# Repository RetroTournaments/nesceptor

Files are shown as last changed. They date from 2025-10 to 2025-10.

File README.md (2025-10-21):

# NESceptor

The NESceptor is a small hardware mod that adds a USB output to a 1985 Nintendo Entertainment System.
This mod is designed to provide support for speedrunning and speedrunning competitions.
The primary use case is to:

 - Allow for live RAM watch
 - Transmit console power status
 - Transmit precise timing information

## Design Decisions

### Why this overall design?

The console is to be treated with respect.
Although nearly [62 million units](https://en.wikipedia.org/wiki/Nintendo_Entertainment_System) were sold, they are no longer manufactured and should not be unnecessarily damaged.
The case (shell) of the Nintendo Entertainment system is _not_ to be cut or irreversibly modified.
The electronics are _not_ to be irreversibly modified.

To satisfy this requirement - while also balancing the desires to be able to quickly install a NESceptor - a two-part design was chosen.
The first board sits inside the console and attaches directly to the back of the CPU via a series of castellations.
This first board provides level translation and hosts the microcontroller which does all necessary i/o and processing.

The second part sits in the small outside slot on the back of the console and is attached via double sided tape and a small cable which goes back to the in console pcb.
This second board has ESD protection and the USB port for power in and data trasmission out.

A rough block diagram is below:

```
                     +--inconsole/--------------------+   +--usbport/---------+
     +------------+  |  +--------+    +------------+  |   |                   |
     |            |  |  |        |    |            |  |   | USB connection    |
     | NES CPU    |  |  | 5V to  |    | Rp2350     |  |   |                   |
     |            |  |  | 3.3V   |    | Micro-     |  |   | ESD protection    |
     | 8 data     |  |  |        |    | controller |  |   |                   |
     | 14 addr    | --> | Level  | -> |            | ---> |                   |
     | 3 aux      |  |  | Trans- |    | Watching / | <--- |                   |
     | --         |  |  | lators |    | Filtering  |  |   |                   |
     | 25 signals |  |  |        |    |            |  |   |                   |
     |            |  |  |        |    |            |  |   |                   |
     +------------+  |  +--------+    +------------+  |   |                   |
                     +--------------------------------+   +-------------------+ 
```

### Why Castellations?

The `inconsole` pcb is connected to the NES CPU with 40 castellations.
Consider:

- Removing the CPU and/or PPU can be difficult for novices (ahem) and requires patience, dedicated tools, and practice.
  Then once removed a socket is installed, and the CPU/PPU have to be installed into yet another socket, and the whole thing is fiddly and may lead to damage.
- The CPU itself is not subjected to heat or potential damage (when removing it), and is left basically alone with this design.
- A flex pcb was tried at one point, but it proved very difficult to install and remove.
  Flex pcbs are also more expensive to manufacture.

The main drawback to the castellations is that they may make the nesceptor difficult to remove, although this has not been tested yet.

### Which signals are needed from the console?

The following signals are absolutely required:

- Data lines 0 to 7 (8 total), these are self explanatory!
- Address lines 0 to 10 and 13-15 (14 total). Address lines 11 and 12 are not necessary because they are [unmapped](https://www.nesdev.org/wiki/CPU_memory_map).
- `NES_RST` when low the console is off, and that is important to know.
- `M2` is the clock
- `R/W` for read / write (low is write) 

This gives a total of 25 signals.

Historically `NMI` was also watched - but it was not used in the first version.
Maybe the controller pins are important, or `IRQ`, but they were never hooked up in the original.

### Notes on level translation

The NES is a 5V system, which is relatively high by modern standards, as most modern microcontrollers only have 3.3V tolerant inputs.
For example the [RP2350 datasheet](https://datasheets.raspberrypi.com/rp2350/rp2350-datasheet.pdf) indicates a maximum 3.63V supply voltage (`IOVDD`) and `IOVDD + 0.3` as maximum input voltage.
The NES signals must be translated to not damage the microcontrollers.

The level translators must not be used to change or interact with the console whatsoever.
They are preferably unidirectional.
This is imperative to maintain the legitimacy of the speedrunning and should be easily verified by third parties.

### Why the RP2350?

An earlier version of the NESceptor used an FPGA - specifically the Lattice iCE40 HX on the Alchitry CU development board, however:

- FPGAs are expensive.
- FPGAs are difficult to program (requiring some HDL).

The RP2350 is cheaper and should be capable of reading the NESs roughly 2 MHz signals:

- [This logic analyzer project](https://github.com/gusmanb/logicanalyzer/tree/master) uses a raspberry pi pico and boasts 100Msps
- And [this one](https://github.com/dotcypress/ula) also gets similar speeds.

### Why USB

USB is simple and well supported, people probably already have a ton of cables.
This will allow for communication and power delivery.
Ethernet is not necessary in this application because the nesbox mini pc will handle that, and would introduce some additional complications when it comes to networking.
Wifi for communication is expected to be unreliable - although this is unknown.

## Dev Instructions

### PCB Development

Install [KiCad](https://www.kicad.org/) for schematics / pcb design / etc.
I just use `snap install kicad`.
This got me `kicad 9.0.1` last time.
I'm using KiCad because it's free, and this is an open source project.

### Enclosure Development

Install [OpenSCAD](https://openscad.org/) for the 3d printed usbport enclosure.
I just use `snap install openscad`.
This got me `openscad 2021.01` last time.
I'm using OpenSCAD because its free, programmatic, and this is an open source project.

### Firmware Development

Firmware is developed using the [RP2350 C/C++ SDK](https://www.raspberrypi.com/documentation/microcontrollers/c_sdk.html).

To get started you need to have cloned this repo with submodules, or else use `git submodule update --init --recursive`.
Install the necessary prerequisites for the pico sdk:

```
sudo apt install cmake gcc-arm-none-eabi libnewlib-arm-none-eabi libstdc++-arm-none-eabi-newlib
```

Then you have to initialize the cmake build system with:

```
mkdir build
cd build
../scripts/cmake.sh
```

Then to build the firmware (source code in `include/` and `src/`), simply use `make`.

To flash the firmware to the nesceptor you need to hold the bootsel button when plugging it in, and then drag and rop the completed `.uf2` file onto the device.
It should then reboot and start running immediately.

### Ordering instructions

Under construction.

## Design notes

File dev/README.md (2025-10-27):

# Dev log

## 2025-10 `testbench/` Design

Round two developing nesceptor begins.
New thoughts:

  - Document more of the development process / decisions.
  - Order everything with PCB assembly.
    I am sick of debugging soldering issues.
    I also want to be able to order more easily - and not have to spend assembly time on my side.

Today I verified that my little TXU0104PWR breakout board worked.
Also, my original connector Molex 5051104091 is on the JLCPCB Parts library!

First item to design / order is a 5051104091 -> Digital discovery adapter that allows for exploration of the signals, and allows hooking up the pico 2 for initial development.
A sort of test bench hence the directory: `testbench/`.

- 5051104091, connector to get all 40 signals from the CPU
- To 5v -> 3.3v level translater prototype
    - TLV1117LV33DCYR for 5v to 3.3v (first test for this part)
    - TXU0104 translators (second implementation of this part)
- To pins with labels (all pins!?)

Review of the connector from my current breakout installed in several NESes

```
5051104091
                    |    |
                    |    |
              40            --  +5V
              39            ->  OUT0
              38            ->  OUT1
------------  37            ->  OUT2 
              36            ->  /OE1  
              35            ->  /OE2  
              34            ->  R/W   
              33            <-  /NMI  
              32            <-  /IRQ
              31            ->  M2
              30            <-  TST (usually GND)
              29            <-  CLK
              28            <>  D0
              27            <>  D1
              26            <>  D2 
              25            <>  D3 
              24            <>  D4 
              23            <>  D5 
              22            <>  D6
              21            <>  D7
 cable        20            --  GND
              19            ->  A15
              18            ->  A14 
              17            ->  A13  
              16            ->  A12   
              15            ->  A11    
              14            ->  A10     
              13            ->  A9      
              12            ->  A8       
              11            ->  A7        
              10            ->  A6         
               9            ->  A5          
               8            ->  A4           
               7            ->  A3            
               6            ->  A2             
               5            ->  A1              
------------   4            ->  A0               
               3            <-  RST
               2            ->  AD2
               1            ->  AD1
                    |    |
                    |    |
```

The rev 1 testbench has a little section for converting the NES 5v to 3.3v, and then some translators to get the signals into the digital discovery.
I ordered it, now to wait for it to show up.

The plan for when it does is to hook it up to the nes and the [Digital Discovery](https://digilent.com/shop/digital-discovery-portable-usb-logic-analyzer-and-digital-pattern-generator/).
This will allow me to document some of the timing information I will need when developing the inconsole firmware.
I have some earlier things kicking around - but they are not in keeping with the new repo structure and philosophy with documenting everything better.

## 2025-10 `inconsole/` -- rev 0

The next pcb I have designed and ordered is a 0th revision for the inconsole.
This is to see if I can fit all the parts, if I can design and order a working RP2350 board, and many other things.

Basically just following the RP2350 hardware design document, and shooting by the hip.
Going to try the RP2354A so I don't have to worry about fitting the flash on there.
I made an initial board which has all the level translation / power stuff contained within the necessary footprint of the NES CPU, and then some extra stuff on the outside for debugging and testing.
I ordered five of these with assembly and will try to learn as many lessons as possible from this.

First few things before it has even shown up.

- Sticking to 0402 components is helpful for assembly and keeping assembly costs down.
  I did 0201 for a bit, but then it was going to require more advanced assembly and higher costs.
- Ensure hole sizes are in tolerance.
- Include the pin 0 on silkscreen to avoid back and forth email.

Waiting for it to show up, and then will test!

## 2025-10 `usbport/` -- rev 0

Before even the other two revision 0s have shown up I'm investigating the `usbport/`.
Essentially I'm just going to steal the design from the [Unified Daughterboard](https://github.com/Unified-Daughterboard/UDB-S) project - which is another open source project primarily for mechanical keyboards.
Unfortunately their original design does not fit exactly where I want this to fit, so I will have to move things around a little bit probably screwing things up in the process.

One other main consideration about the usbport is that it needs a little enclosure to keep everything neat and tidy and protected.
I was originally thinking of coming out the left of the console - but we have power out the back, and composite out the right, so would be better to not add another cable out another side.
Then I ordered a unified daughterboard just to test, and the Pico EZMate connector is so small that it fits out the expansion port directly, and does not need to come out the vents.
Going to try for out the back on the 0th revision.

The back slot is about 99mm long, 12.5mm deep, ~16 mm wide (15.9 at 'top', 16.5 at 'bottom').
Let's imagine then 1.5mm thick walls on both sides, gives me a 12 mm wide pcb, 1.6mm thick.
I do not think I need to go the full length, but it would make it a bit easier for pushing the usb cable in to have some backing.
Regardless the PCB itself does not need to go to the back.

In keeping with stealing from the unified daughterboard project, we'll be using this [usb c connector - C165948](https://jlcpcb.com/partdetail/Korean_HropartsElec-TYPE_C_31_M12/C165948).

For the enclosure thinking of starting with a single hole in the middle M3 with [threaded inserts](https://www.mcmaster.com/products/threaded-inserts/threaded-inserts-3~/tapered-heat-set-inserts-for-plastic-7/).

## 2025-10 `inconsole/` -- rev 0 continued

The inconsole prototype showed up first and incredibly the RP2354a is actually working??
Just straight up plugged in the usb via a unified daughterboard (because my usbport rev is not done), and it just booted up with no problems..
Then I was able to install my own firmware - just a hello world thing, and it worked? Like uhhhhh. Insane!

> Rev 1 - Include the bootsel button within the final design. Actually no, the boot at 1200 baud does it.
> Rev 1 - Have not needed the run button or the debug port yet.

Now I need to test the 5V level translation part, and actually read the GPIO.
I wrote a small program (in this commit), and then just by shorting the RST pin to 5V with a little jumper cable it works.
No smoke either.
I just think everything is working?
We do have to get into the nitty gritty with timing and stuff now.
Hopefully testbench shows up - do I need to do some PIO stuff here?

## 2025-10 Wires
I ordered 200 25cm wires from [here](https://www.alibaba.com/product-detail/Customized-Molex-EZmate-78171-78172-1_1600697379284.html).
Hopefully long enough, and correct!

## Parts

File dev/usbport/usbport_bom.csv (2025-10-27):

Value | Designator | Footprint | LCSC Part Number
ESD5Z5V0 | D1 | Diode_SMD:D_SOD-523 | C727161
SMD0805-050-16V | F1 | Fuse_1206_3216Metric | C968441
GZ2012D601TF | FB1 | Inductor_SMD:L_0805_2012Metric | C1017
USB_C_Receptacle_USB2.0_16P | J1 | HRO-TYPE-C-31-M-12-Assembly | C165948
Conn_01x04_MountingPin | J2 | PicoEZMate-Reinforced-Lite | C588524
5.1k | R1,R2 | Resistor_SMD:R_0402_1005Metric | C25905
TPD4E05U06DQAR | U1 | USON-10_2.5x1.0mm_P0.5mm | C2836386

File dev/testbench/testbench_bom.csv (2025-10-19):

Comment | Designator | Footprint | LCSC Part Number
1uF | C1,C16 | 0805 | C1712
.1uF | C2,C3,C4,C5,C6,C7,C8,C9,C10,C11,C12,C13,C14,C15 | 0402 | C1525
5051104091 | J1 | 5051104091 | C588009
TXU0104BQAR | U1,U2,U3,U4,U5,U6,U7 | WQFN-14 | C4354911
TLV1117LV33DCYR | U8 | SOT-223 | C15578

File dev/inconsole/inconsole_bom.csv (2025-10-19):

Comment | Designator | Footprint | LCSC Part Number
10u | C1,C19 | C_0805 | C15850
.1uF | C2,C3,C4,C5,C6,C7,C8,C9,C10,C11,C12,C13,C14,C15,C24,C25,C26,C27,C28,C29,C30,C31,C32 | C_0402 | C1525
4.7uF | C16,C17,C18,C22 | C_0402 | C76995
15p | C20,C21 | C_0402 | C1548
Conn_01x04_MountingPin | J1 | PicoEZMate | C588524
5051104091 | J2 | 5051104091 | C588009
SM03B-SRSS-TB | J4 | SMD | C160403
AOTA-B201610S3R3-101-T | L1 | L_0806 | C42411119
33R | R1 | R_0402 | C25105
1k | R2,R4,R6 | R_0402 | C11702
27R | R7,R8 | R_0402 | C25100
SW_Push | SW1,SW2 | SMD4x3mm | C720477
TXU0104RUTR | U2,U3,U4,U5,U6,U7,U9 | UQFN-12(1.7x2) | C5187176
RP2354A | U8 | QFN-60(7x7) | C41378174
NCP1117ST33T3G | U11 | SOT-223 | C26537
ABM8-272-T3 | Y1 | SMD3225-4P | C20625731

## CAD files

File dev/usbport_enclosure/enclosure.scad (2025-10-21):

pcb_length = 35;
pcb_width = 12;
pcb_hole = 18;
pcb_thickness = 1.6;

module rounded_rect(uw, uh, ul, ur, fn) {
    union() {
        translate([ur, ur, 0]) {
            cylinder(h=ul, r=ur, center=false, $fn=fn);
        }
        translate([uw-ur, ur, 0]) {
            cylinder(h=ul, r=ur, center=false, $fn=fn);
        }
        translate([ur, uh-ur, 0]) {
            cylinder(h=ul, r=ur, center=false, $fn=fn);
        }
        translate([uw-ur, uh-ur, 0]) {
            cylinder(h=ul, r=ur, center=false, $fn=fn);
        }
        translate([0, ur, 0]) {
            cube([uw, uh-2*ur, ul]);
        }
        translate([ur, 0, 0]) {
            cube([uw-2*ur, uh, ul]);
        }
    }
}

module usbport() {
    // The PCB
    difference() {
        cube([pcb_length, pcb_width, pcb_thickness]);
        
        translate([pcb_hole, 6, 0.8]) {
            cylinder(h=4, d=3.2, center=true, $fn=16);
        }
    }
    
    // The USB C Port
    uw = 8.94;
    translate([-1, (pcb_width-uw)/2, pcb_thickness]) {
        rotate([90, 0, 90]) {
            rounded_rect(uw, 3.26, 7.35, (3.26 - 0.7) / 2, 16);
        }
    }
    
}


module nes_bottom() {
    nw = 270;
    nl = 240;
    nh = 50;
    difference() {
        // The full bottom
        cube([nl, nw, nh]);
        
        // The 2 degree tapers on the front and back
        translate([0, -5, nh]) {
            mirror([1, 0, 0]) {
                rotate([0, 92, 0]) {
                    cube([55, nw+10, 10]);
                }
            }
        }
        translate([nl, -5, nh]) {
            rotate([0, 92, 0]) {
                cube([55, nw+10, 10]);
            }
        }
        
        // the 22 degree tapers on the left and right
        translate([-5, 0, nh-12]) {
            mirror([0, 0, 1]) {
                rotate([68, 0, 0]) {
                    cube([nl+10, 50, 25]);
                }
            }
        }
        translate([-5, nw, nh-12]) {
            mirror([0, 0, 0]) {
                rotate([68+180, 0, 0]) {
                    cube([nl+10, 50, 25]);
                }
            }
        }
        
        // the bottom slot
        hull() {
            translate([0, 101, -0.1]) {
                cube([100, 16.5, 0.1]);
                translate([0, 0.25, 12.6]) {
                    cube([100, 16, 0.1]);
                }
            }
        }
    }
}


// Approx outer box dimensions
enc_length = 40;
enc_width = 15;
enc_height = 11.5;

// Inner box dimensions
wall_size = 1.2; // front and back
// width uses 'pcb_width'
pcb_off = 0.15;
inner_width = pcb_width + pcb_off * 2;
pcb_ledge = 1;
ledge_width = pcb_width - pcb_ledge * 2;

pcb_height = 4;

module threaded_insert() {
    h = 4;
    v = tan(8) * h;
    cylinder(h=h, r1=2.525 + v/2, r2=2.525 - v/2, $fn=30);
}

cut_height = enc_height *3/4;

module enc() {
    // distance to expand top of box forward to match the slight NES angle
    front_off = 0.4;
    // distance to shrink top inwards to match the NES angle
    top_off = 0.5;
    
    // outside boundary
    difference() {
        union() {
            difference() {
                // the main outside area
                hull() {
                    cube([enc_length, enc_width, 0.001]);
                    translate([-front_off, top_off / 2, enc_height]) {
                        cube([enc_length + front_off, enc_width-top_off, 0.001]);
                    }
                }
                // Upper inner section
                translate([wall_size, (enc_width-inner_width) / 2, pcb_height]) {
                    cube([enc_length-wall_size*2, inner_width, enc_height-(pcb_height + wall_size)]);
                }
                // Lower inner section
                translate([wall_size, (enc_width-ledge_width) / 2, wall_size]) {
                    cube([enc_length-wall_size*2, ledge_width, enc_height-(pcb_height + wall_size)]);
                }

                // The front usb port
                uw = 9.2;
                uh = 3.4;
                translate([-1, (enc_width-uw)/2, pcb_height + pcb_thickness]) {
                    rotate([90, 0, 90]) {
                        rounded_rect(uw, uh, 7.35, (uh - 0.8) / 2, 30);
                    }
                }
                // The back port
                bw = 6;
                bh = 2;
                translate([enc_length-wall_size - 1, (enc_width-bw)/2,
                    cut_height - bh/2 + -0.2]) {
                    rotate([90, 0, 90]) {
                        rounded_rect(bw, bh, 7.35, bh / 2, 30);
                    }
                }
            }
            
            // under pcb hole support
            support_r = 4.5;
            translate([pcb_hole + wall_size, enc_width/2, 0]) {
                cylinder(h=pcb_height, r=support_r, center=false, $fn=120);
            }
            
            // above pcb threaded insert
            translate([pcb_hole + wall_size, enc_width/2, pcb_height + pcb_thickness]) {
                difference() {
                    cylinder(h=enc_height - pcb_height - pcb_thickness, r=support_r, center=false, $fn=120);
                    translate([0, 0, -0.001]) {
                        threaded_insert();
                    }
                }
            }
            
        }
        // The slot for the screw head
        translate([pcb_hole + wall_size, enc_width/2, -0.1]) {
            cylinder(h=3.1, r=3, $fn=120);
        }
        // The screw hole
        translate([pcb_hole + wall_size, enc_width/2, -0.1]) {
            cylinder(h=pcb_height + 0.2, r=1.6, $fn=120);
        }
    }
}

module cutter() {
    union() {
        // The main split into two
        translate([wall_size+0.001, -10, cut_height]) {
            cube([enc_length, enc_width+20, enc_height]);
        }
        
        // cut out for a kinda snap together lip? maybe too thin
        /*
        translate([wall_size + 0.001, wall_size / 2 + 0.3, enc_height * 3/4 - 0.4]){
            cube([enc_length - wall_size * 2 + wall_size * 0.5, 
            enc_width - wall_size - 0.6, 10]);
        }
        */
        
        // to support the above pcb threaded insert
        translate([pcb_hole + wall_size - 5, enc_width/2 - 5, pcb_height + pcb_thickness / 2]) {
            cube(10);
        }
    }
}

/*
rotate([-90, 0, 0]) {
*/

//translate([wall_size, (enc_width-pcb_width) / 2, pcb_height]) usbport();
//translate([-1.8, -101.7, 0]) nes_bottom();

/*
translate([0, 40, enc_height]) {
    rotate([180, 0, 0]) {
        intersection() {
            enc();
            cutter();
        }
    }
}
*/

difference() {
    enc();
    cutter();
}


//cutter();
/*
}
*/

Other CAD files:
dev/usbport_enclosure/top.stl
dev/usbport_enclosure/bottom.stl

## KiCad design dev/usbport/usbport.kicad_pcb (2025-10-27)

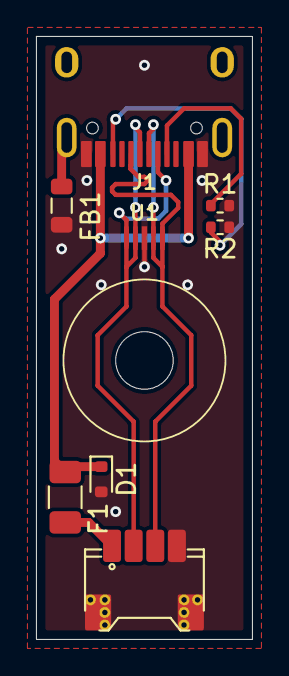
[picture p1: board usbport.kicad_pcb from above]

Board: 2 copper layers, 12.0 x 33.5 mm, 9 parts (0 on the bottom side), 8 nets.

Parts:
D1: ESD5Z5V0; D_SOD-523
F1: SMD0805-050-16V; Fuse_1206_3216Metric
FB1: GZ2012D601TF; L_0805_2012Metric
H1: MountingHole; MountingHole_3.2mm_M3
J1: USB_C_Receptacle_USB2.0_16P; HRO-TYPE-C-31-M-12-Assembly
J2: Conn_01x04_MountingPin; PicoEZMate-Reinforced-Lite
R1, R2: 5.1k; R_0402_1005Metric
U1: TPD4E05U06DQAR; USON-10_2.5x1.0mm_P0.5mm

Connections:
+5V: F1.2, J2.1
D+: J1.A6 (D+), J1.B6 (D+), J2.3, U1.4 (D2+), U1.5 (D2-), U1.6 (NC), U1.7 (NC)
D-: J1.A7 (D-), J1.B7 (D-), J2.2, U1.1 (IO1), U1.2 (IO2), U1.9 (NC), U1.10 (NC)
GND: D1.2 (A2), FB1.2, J1.A1 (GND), J1.B1 (GND), J2.4, J2.MP (MountPin), R1.1, R2.2, U1.3 (GND), U1.8 (GND)
GNDPWR: FB1.1, J1.S1 (SHIELD)
unnamed: J1.A5 (CC1), R1.2
unnamed: J1.B5 (CC2), R2.1
VBUS: D1.1 (A1), F1.1, J1.A4 (VBUS), J1.B4 (VBUS)

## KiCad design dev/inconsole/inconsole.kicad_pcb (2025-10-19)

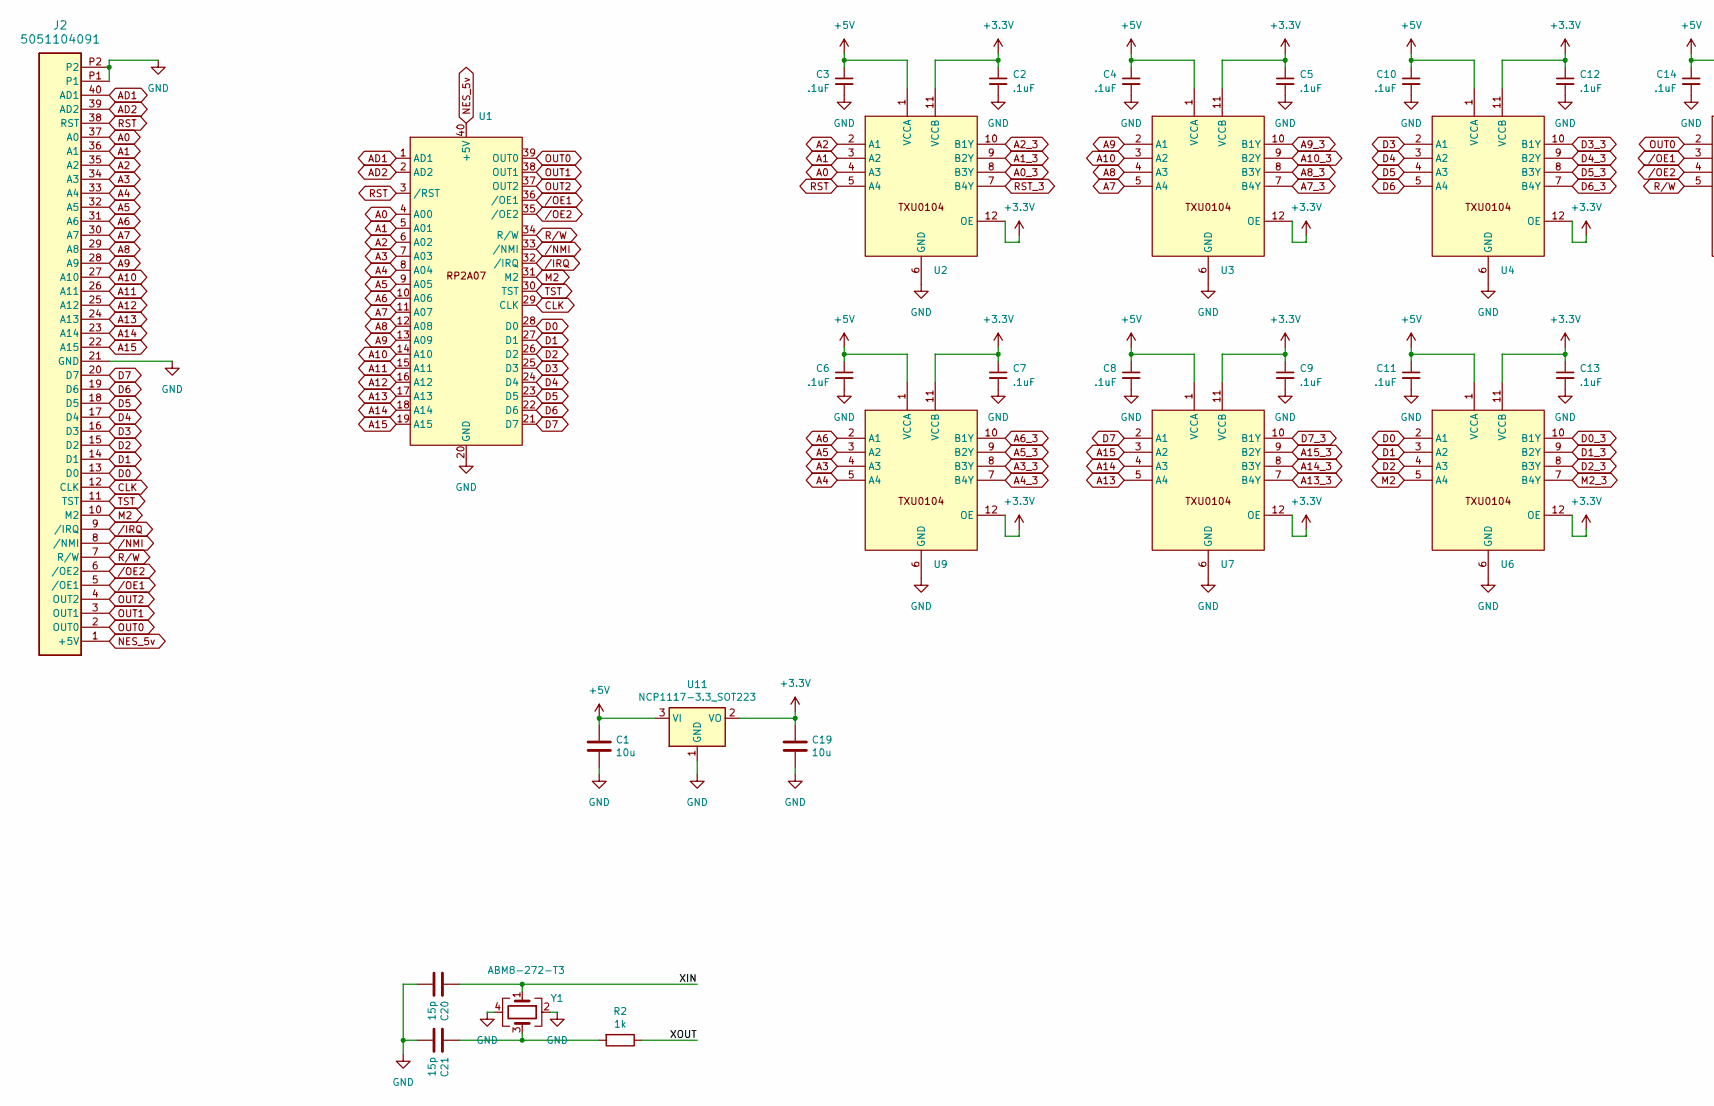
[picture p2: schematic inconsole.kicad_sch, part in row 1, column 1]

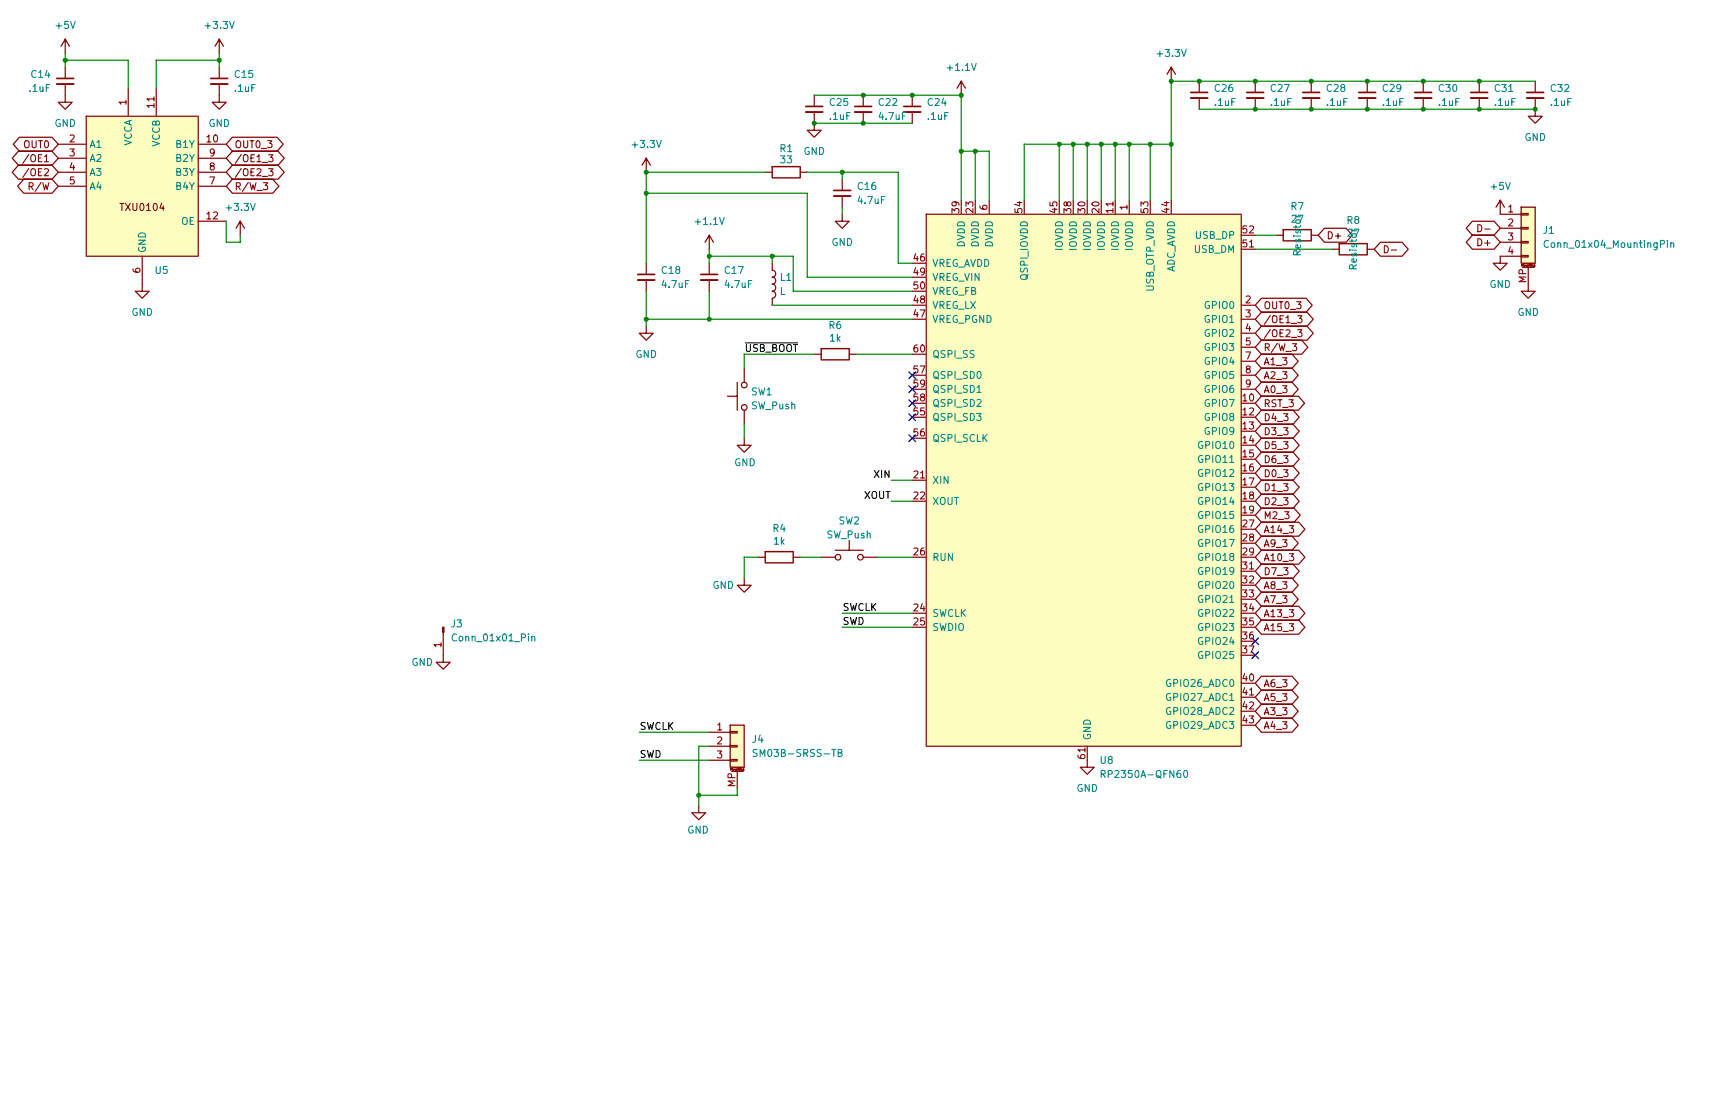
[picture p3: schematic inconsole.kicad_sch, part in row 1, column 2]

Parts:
C1, C19: 10u; C_0805_2012Metric
C2, C3, C4, C5, C6, C7, C8, C9, C10, C11, C12, C13, C14, C15, C24, C25, C26, C27, C28, C29, C30, C31, C32: .1uF; C_0402_1005Metric
C16, C17, C18, C22: 4.7uF; C_0402_1005Metric
C20, C21: 15p; C_0402_1005Metric
J1: Conn_01x04_MountingPin; PicoEZMate-Reinforced-Lite; Manufacturer Part Number 78171-0004; LCSC Part Number C588524
J2: 5051104091; CON_5051104091_MOL
J3: Conn_01x01_Pin; PinSocket_1x01_P2.54mm_Vertical
J4: SM03B-SRSS-TB; JST_SH_SM03B-SRSS-TB_1x03-1MP_P1.00mm_Horizontal
L1: L; AOTA-B201610S3R3-101-T
R1: 33; C_0402_1005Metric
R2, R6: 1k; C_0402_1005Metric
R4: 1k; R_0402_1005Metric
R7, R8: 27; C_0402_1005Metric
SW1, SW2: SW_Push; TS-1088-AR02016
U1: RP2A07
U2, U3, U4, U5, U6, U7, U9: PQFP12_RUT_TEX
U8: RP2350A-QFN60; RP2350A_QFN-60_EP_7.75x7.75_Pitch0.4mm
U11: NCP1117-3.3_SOT223; SOT-223-3_TabPin2
Y1: ABM8-272-T3; Crystal_SMD_3225-4Pin_3.2x2.5mm

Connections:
+1.1V: C17.1, C22.1, C24.1, C25.1, L1.1, U8.6 (DVDD), U8.23 (DVDD), U8.39 (DVDD), U8.50 (VREG_FB)
+3.3V: C2.1, C5.1, C7.1, C9.1, C12.1, C13.1, C15.1, C18.1, C19.1, C26.1, C27.1, C28.1, C29.1, C30.1, C31.1, C32.1, R1.2, U2.11 (VCCB), U2.12 (OE), U3.11 (VCCB), U3.12 (OE), U4.11 (VCCB), U4.12 (OE), U5.11 (VCCB), U5.12 (OE), U6.11 (VCCB), U6.12 (OE), U7.11 (VCCB), U7.12 (OE), U8.1 (IOVDD), U8.11 (IOVDD), U8.20 (IOVDD), U8.30 (IOVDD), U8.38 (IOVDD), U8.44 (ADC_AVDD), U8.45 (IOVDD), U8.49 (VREG_VIN), U8.53 (USB_OTP_VDD), U8.54 (QSPI_IOVDD), U9.11 (VCCB), U9.12 (OE), U11.2 (VO)
+5V: C1.1, C3.1, C4.1, C6.1, C8.1, C10.1, C11.1, C14.1, J1.1, U2.1 (VCCA), U3.1 (VCCA), U4.1 (VCCA), U5.1 (VCCA), U6.1 (VCCA), U7.1 (VCCA), U9.1 (VCCA), U11.3 (VI)
/SWCLK: J4.1, U8.24 (SWCLK)
/SWD: J4.3, U8.25 (SWDIO)
/XIN: C20.1, U8.21 (XIN), Y1.1
/XOUT: R2.1, U8.22 (XOUT)
/~USB_BOOT: R6.2, SW1.2
A0: J2.37 (A0), U1.4 (A00), U2.4 (A3)
A0_3: U2.8 (B3Y), U8.9 (GPIO6)
A1: J2.36 (A1), U1.5 (A01), U2.3 (A2)
A1_3: U2.9 (B2Y), U8.7 (GPIO4)
A2: J2.35 (A2), U1.6 (A02), U2.2 (A1)
A2_3: U2.10 (B1Y), U8.8 (GPIO5)
A3: J2.34 (A3), U1.7 (A03), U9.4 (A3)
A3_3: U8.42 (GPIO28_ADC2), U9.8 (B3Y)
A4: J2.33 (A4), U1.8 (A04), U9.5 (A4)
A4_3: U8.43 (GPIO29_ADC3), U9.7 (B4Y)
A5: J2.32 (A5), U1.9 (A05), U9.3 (A2)
A5_3: U8.41 (GPIO27_ADC1), U9.9 (B2Y)
A6: J2.31 (A6), U1.10 (A06), U9.2 (A1)
A6_3: U8.40 (GPIO26_ADC0), U9.10 (B1Y)
A7: J2.30 (A7), U1.11 (A07), U3.5 (A4)
A7_3: U3.7 (B4Y), U8.33 (GPIO21)
A8: J2.29 (A8), U1.12 (A08), U3.4 (A3)
A8_3: U3.8 (B3Y), U8.32 (GPIO20)
A9: J2.28 (A9), U1.13 (A09), U3.2 (A1)
A9_3: U3.10 (B1Y), U8.28 (GPIO17)
A10: J2.27 (A10), U1.14 (A10), U3.3 (A2)
A10_3: U3.9 (B2Y), U8.29 (GPIO18)
A11: J2.26 (A11), U1.15 (A11)
A12: J2.25 (A12), U1.16 (A12)
A13: J2.24 (A13), U1.17 (A13), U7.5 (A4)
A13_3: U7.7 (B4Y), U8.34 (GPIO22)
A14: J2.23 (A14), U1.18 (A14), U7.4 (A3)
A14_3: U7.8 (B3Y), U8.27 (GPIO16)
A15: J2.22 (A15), U1.19 (A15), U7.3 (A2)
A15_3: U7.9 (B2Y), U8.35 (GPIO23)
AD1: J2.40 (AD1), U1.1 (AD1)
AD2: J2.39 (AD2), U1.2 (AD2)
CLK: J2.12 (CLK), U1.29 (CLK)
D0: J2.13 (D0), U1.28 (D0), U6.2 (A1)
D0_3: U6.10 (B1Y), U8.16 (GPIO12)
D1: J2.14 (D1), U1.27 (D1), U6.3 (A2)
D1_3: U6.9 (B2Y), U8.17 (GPIO13)
D2: J2.15 (D2), U1.26 (D2), U6.4 (A3)
D2_3: U6.8 (B3Y), U8.18 (GPIO14)
D3: J2.16 (D3), U1.25 (D3), U4.2 (A1)
D3_3: U4.10 (B1Y), U8.13 (GPIO9)
D4: J2.17 (D4), U1.24 (D4), U4.3 (A2)
D4_3: U4.9 (B2Y), U8.12 (GPIO8)
D5: J2.18 (D5), U1.23 (D5), U4.4 (A3)
D5_3: U4.8 (B3Y), U8.14 (GPIO10)
D6: J2.19 (D6), U1.22 (D6), U4.5 (A4)
D6_3: U4.7 (B4Y), U8.15 (GPIO11)
D7: J2.20 (D7), U1.21 (D7), U7.2 (A1)
D7_3: U7.10 (B1Y), U8.31 (GPIO19)
D+: J1.3, R7.1
D-: J1.2, R8.1
GND: C1.2, C2.2, C3.2, C4.2, C5.2, C6.2, C7.2, C8.2, C9.2, C10.2, C11.2, C12.2, C13.2, C14.2, C15.2, C16.2, C17.2, C18.2, C19.2, C20.2, C21.2, C22.2, C24.2, C25.2, C26.2, C27.2, C28.2, C29.2, C30.2, C31.2, C32.2, J1.4, J1.MP (MountPin), J2.21 (GND), J2.P1, J2.P2, J3.1, J4.2, J4.MP (MountPin), R4.2, SW1.1, U1.20 (GND), U2.6 (GND), U3.6 (GND), U4.6 (GND), U5.6 (GND), U6.6 (GND), U7.6 (GND), U8.47 (VREG_PGND), U8.61 (GND), U9.6 (GND), U11.1 (GND), Y1.2, Y1.4
M2: J2.10 (M2), U1.31 (M2), U6.5 (A4)
M2_3: U6.7 (B4Y), U8.19 (GPIO15)
NES_5v: J2.1 (+5V), U1.40 (+5V)
unnamed: C21.1, R2.2, Y1.3
unnamed: R4.1, SW2.1
unnamed: R6.1, U8.60 (QSPI_SS)
unnamed: SW2.2, U8.26 (RUN)
unnamed: R8.2, U8.51 (USB_DM)
unnamed: R7.2, U8.52 (USB_DP)
unnamed: C16.1, R1.1, U8.46 (VREG_AVDD)
unnamed: L1.2, U8.48 (VREG_LX)
OUT0: J2.2 (OUT0), U1.39 (OUT0), U5.2 (A1)
OUT0_3: U5.10 (B1Y), U8.2 (GPIO0)
OUT1: J2.3 (OUT1), U1.38 (OUT1)
OUT2: J2.4 (OUT2), U1.37 (OUT2)
RST: J2.38 (RST), U1.3 (/RST), U2.5 (A4)
RST_3: U2.7 (B4Y), U8.10 (GPIO7)
R/W: J2.7 (R/W), U1.34 (R/W), U5.5 (A4)
R/W_3: U5.7 (B4Y), U8.5 (GPIO3)
TST: J2.11 (TST), U1.30 (TST)
/IRQ: J2.9 (/IRQ), U1.32 (/IRQ)
/NMI: J2.8 (/NMI), U1.33 (/NMI)
/OE1: J2.5 (/OE1), U1.36 (/OE1), U5.3 (A2)
/OE1_3: U5.9 (B2Y), U8.3 (GPIO1)
/OE2: J2.6 (/OE2), U1.35 (/OE2), U5.4 (A3)
/OE2_3: U5.8 (B3Y), U8.4 (GPIO2)

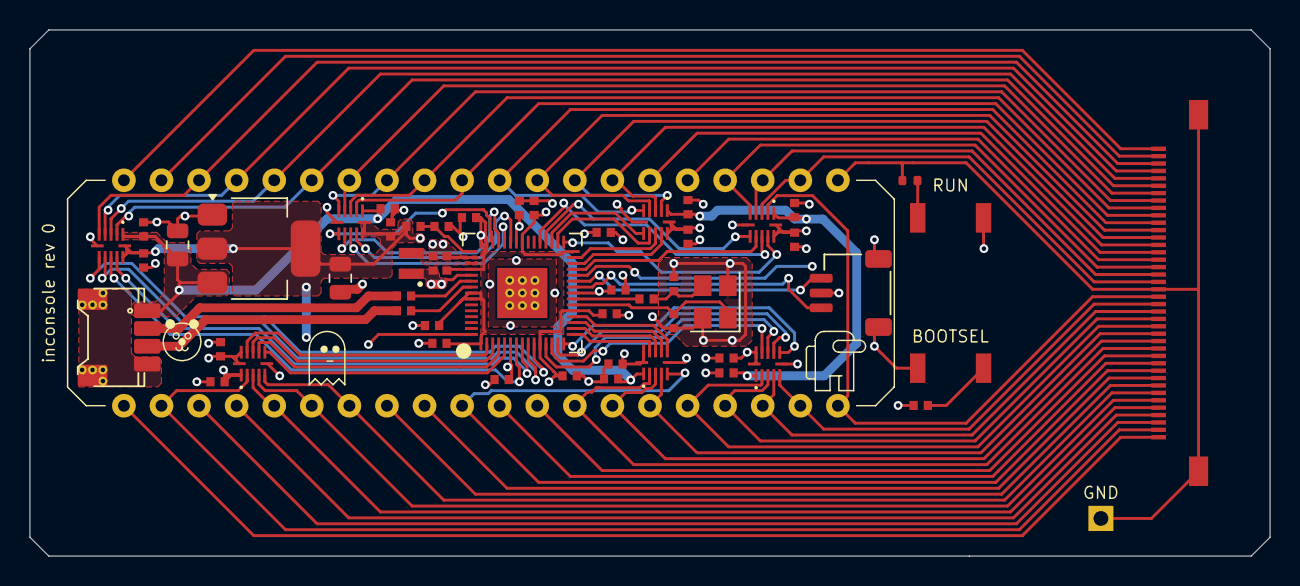
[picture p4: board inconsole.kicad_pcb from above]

Board: 4 copper layers, 83.8 x 35.6 mm, 55 parts (1 on the bottom side), 86 nets.

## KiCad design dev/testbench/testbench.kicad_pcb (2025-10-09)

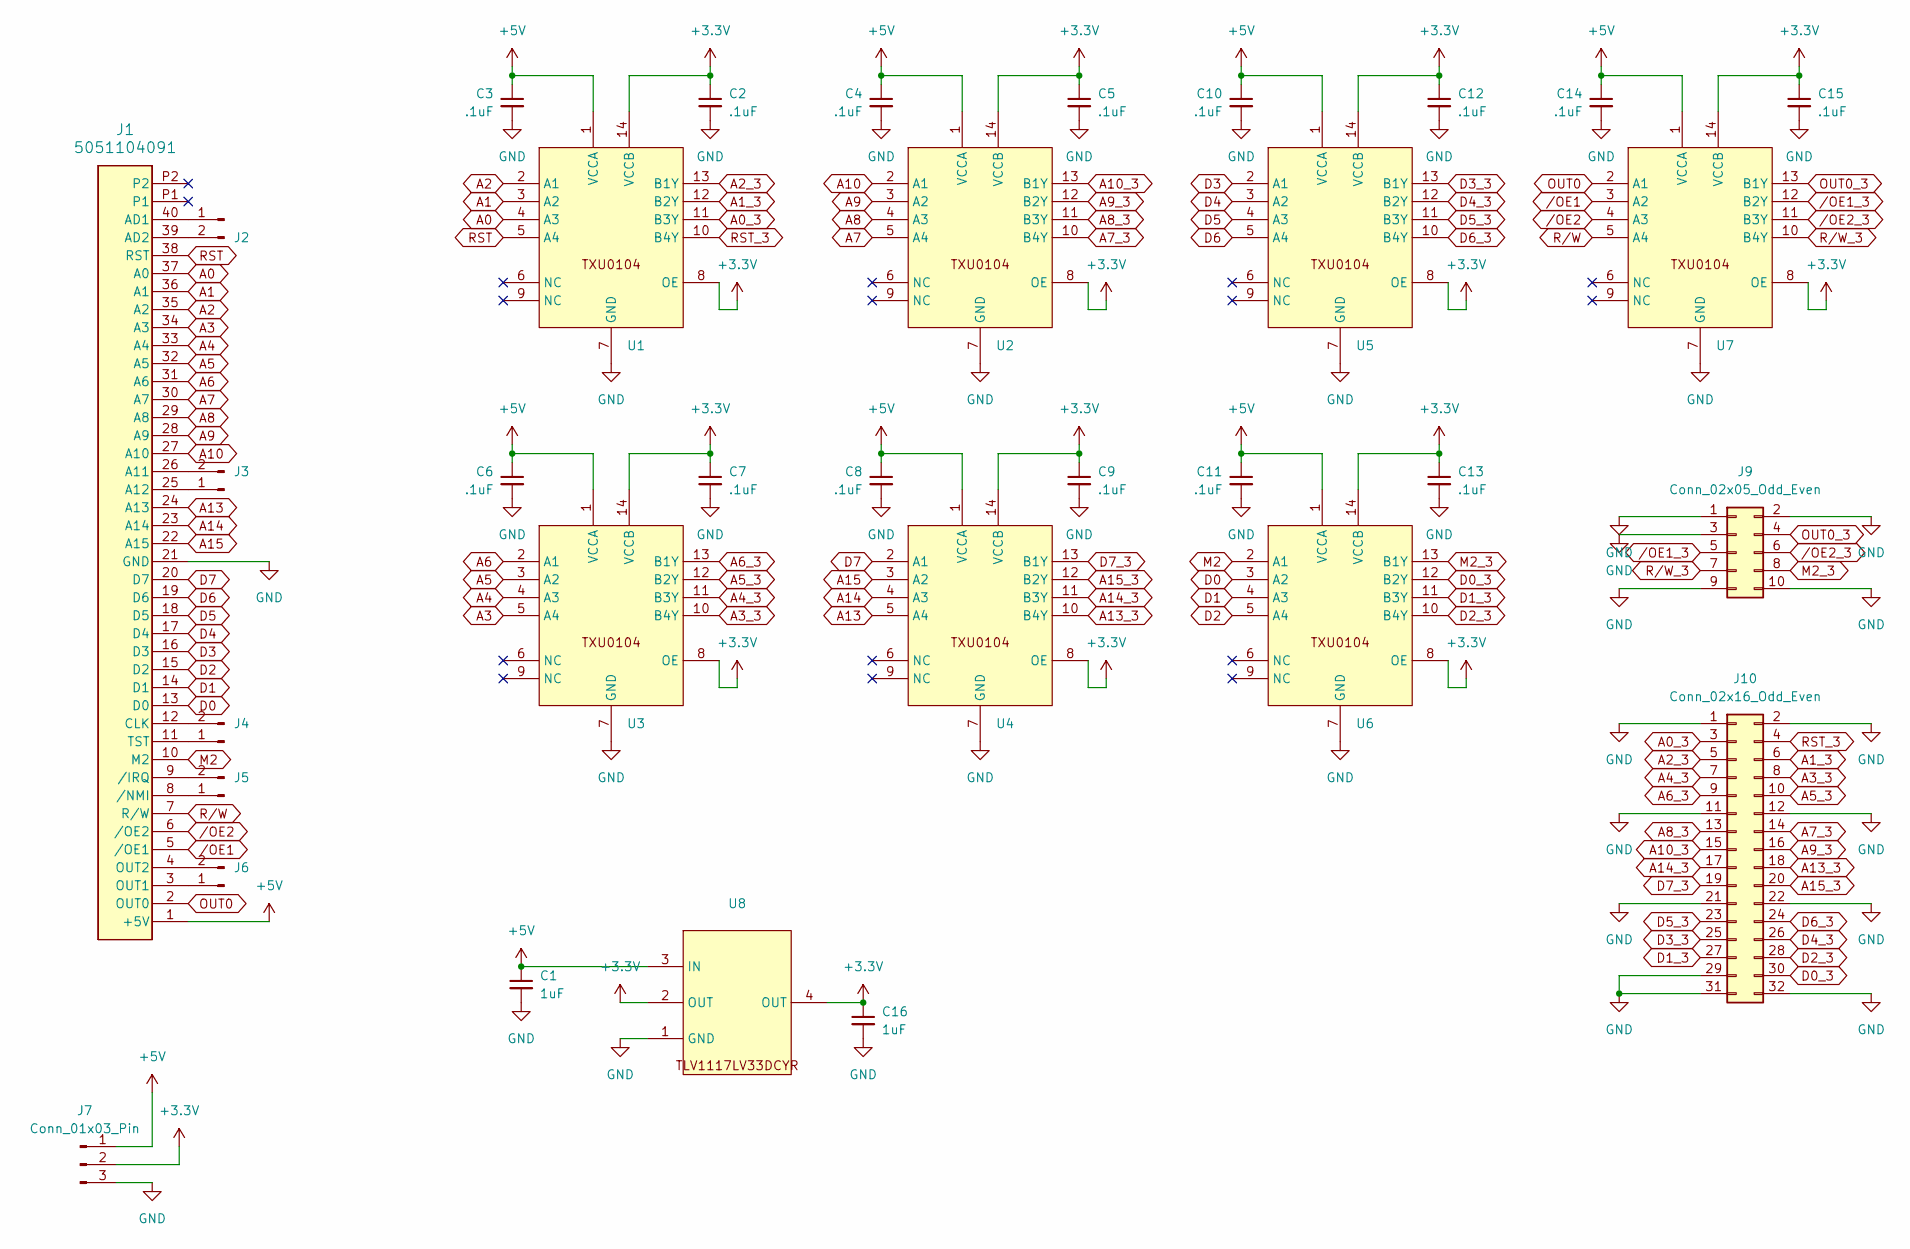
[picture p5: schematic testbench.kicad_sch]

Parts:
C1, C16: 1uF; C_0805_2012Metric
C2, C3, C4, C5, C6, C7, C8, C9, C10, C11, C12, C13, C14, C15: .1uF; C_0402_1005Metric
J1: 5051104091; CON_5051104091_MOL
J2, J3, J4, J5, J6: Conn_01x02_Pin; PinHeader_1x02_P2.54mm_Vertical
J7: Conn_01x03_Pin; PinHeader_1x03_P2.54mm_Vertical
J9: Conn_02x05_Odd_Even; PinHeader_2x05_P2.54mm_Vertical
J10: Conn_02x16_Odd_Even; PinHeader_2x16_P2.54mm_Vertical
U1, U2, U3, U4, U5, U6, U7: DHVQFN-14-1EP_2.5x3mm_P0.5mm_EP1x1.5mm
U8: SOT-223

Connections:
+3.3V: C2.1, C5.1, C7.1, C9.1, C12.1, C13.1, C15.1, C16.1, J7.2, U1.8 (OE), U1.14 (VCCB), U2.8 (OE), U2.14 (VCCB), U3.8 (OE), U3.14 (VCCB), U4.8 (OE), U4.14 (VCCB), U5.8 (OE), U5.14 (VCCB), U6.8 (OE), U6.14 (VCCB), U7.8 (OE), U7.14 (VCCB), U8.2 (OUT), U8.4 (OUT)
+5V: C1.1, C3.1, C4.1, C6.1, C8.1, C10.1, C11.1, C14.1, J1.1 (+5V), J7.1, U1.1 (VCCA), U2.1 (VCCA), U3.1 (VCCA), U4.1 (VCCA), U5.1 (VCCA), U6.1 (VCCA), U7.1 (VCCA), U8.3 (IN)
A0: J1.37 (A0), U1.4 (A3)
A0_3: J10.3, U1.11 (B3Y)
A1: J1.36 (A1), U1.3 (A2)
A1_3: J10.6, U1.12 (B2Y)
A2: J1.35 (A2), U1.2 (A1)
A2_3: J10.5, U1.13 (B1Y)
A3: J1.34 (A3), U3.5 (A4)
A3_3: J10.8, U3.10 (B4Y)
A4: J1.33 (A4), U3.4 (A3)
A4_3: J10.7, U3.11 (B3Y)
A5: J1.32 (A5), U3.3 (A2)
A5_3: J10.10, U3.12 (B2Y)
A6: J1.31 (A6), U3.2 (A1)
A6_3: J10.9, U3.13 (B1Y)
A7: J1.30 (A7), U2.5 (A4)
A7_3: J10.14, U2.10 (B4Y)
A8: J1.29 (A8), U2.4 (A3)
A8_3: J10.13, U2.11 (B3Y)
A9: J1.28 (A9), U2.3 (A2)
A9_3: J10.16, U2.12 (B2Y)
A10: J1.27 (A10), U2.2 (A1)
A10_3: J10.15, U2.13 (B1Y)
A13: J1.24 (A13), U4.5 (A4)
A13_3: J10.18, U4.10 (B4Y)
A14: J1.23 (A14), U4.4 (A3)
A14_3: J10.17, U4.11 (B3Y)
A15: J1.22 (A15), U4.3 (A2)
A15_3: J10.20, U4.12 (B2Y)
D0: J1.13 (D0), U6.3 (A2)
D0_3: J10.30, U6.12 (B2Y)
D1: J1.14 (D1), U6.4 (A3)
D1_3: J10.27, U6.11 (B3Y)
D2: J1.15 (D2), U6.5 (A4)
D2_3: J10.28, U6.10 (B4Y)
D3: J1.16 (D3), U5.2 (A1)
D3_3: J10.25, U5.13 (B1Y)
D4: J1.17 (D4), U5.3 (A2)
D4_3: J10.26, U5.12 (B2Y)
D5: J1.18 (D5), U5.4 (A3)
D5_3: J10.23, U5.11 (B3Y)
D6: J1.19 (D6), U5.5 (A4)
D6_3: J10.24, U5.10 (B4Y)
D7: J1.20 (D7), U4.2 (A1)
D7_3: J10.19, U4.13 (B1Y)
GND: C1.2, C2.2, C3.2, C4.2, C5.2, C6.2, C7.2, C8.2, C9.2, C10.2, C11.2, C12.2, C13.2, C14.2, C15.2, C16.2, J1.21 (GND), J7.3, J9.1, J9.2, J9.3, J9.9, J9.10, J10.1, J10.2, J10.11, J10.12, J10.21, J10.22, J10.29, J10.31, J10.32, U1.7 (GND), U2.7 (GND), U3.7 (GND), U4.7 (GND), U5.7 (GND), U6.7 (GND), U7.7 (GND), U8.1 (GND)
M2: J1.10 (M2), U6.2 (A1)
M2_3: J9.8, U6.13 (B1Y)
unnamed: J1.26 (A11), J3.2
unnamed: J1.25 (A12), J3.1
unnamed: J1.40 (AD1), J2.1
unnamed: J1.39 (AD2), J2.2
unnamed: J1.12 (CLK), J4.2
unnamed: J1.3 (OUT1), J6.1
unnamed: J1.4 (OUT2), J6.2
unnamed: J1.11 (TST), J4.1
unnamed: J1.9 (/IRQ), J5.2
unnamed: J1.8 (/NMI), J5.1
OUT0: J1.2 (OUT0), U7.2 (A1)
OUT0_3: J9.4, U7.13 (B1Y)
RST: J1.38 (RST), U1.5 (A4)
RST_3: J10.4, U1.10 (B4Y)
R/W: J1.7 (R/W), U7.5 (A4)
R/W_3: J9.7, U7.10 (B4Y)
/OE1: J1.5 (/OE1), U7.3 (A2)
/OE1_3: J9.5, U7.12 (B2Y)
/OE2: J1.6 (/OE2), U7.4 (A3)
/OE2_3: J9.6, U7.11 (B3Y)

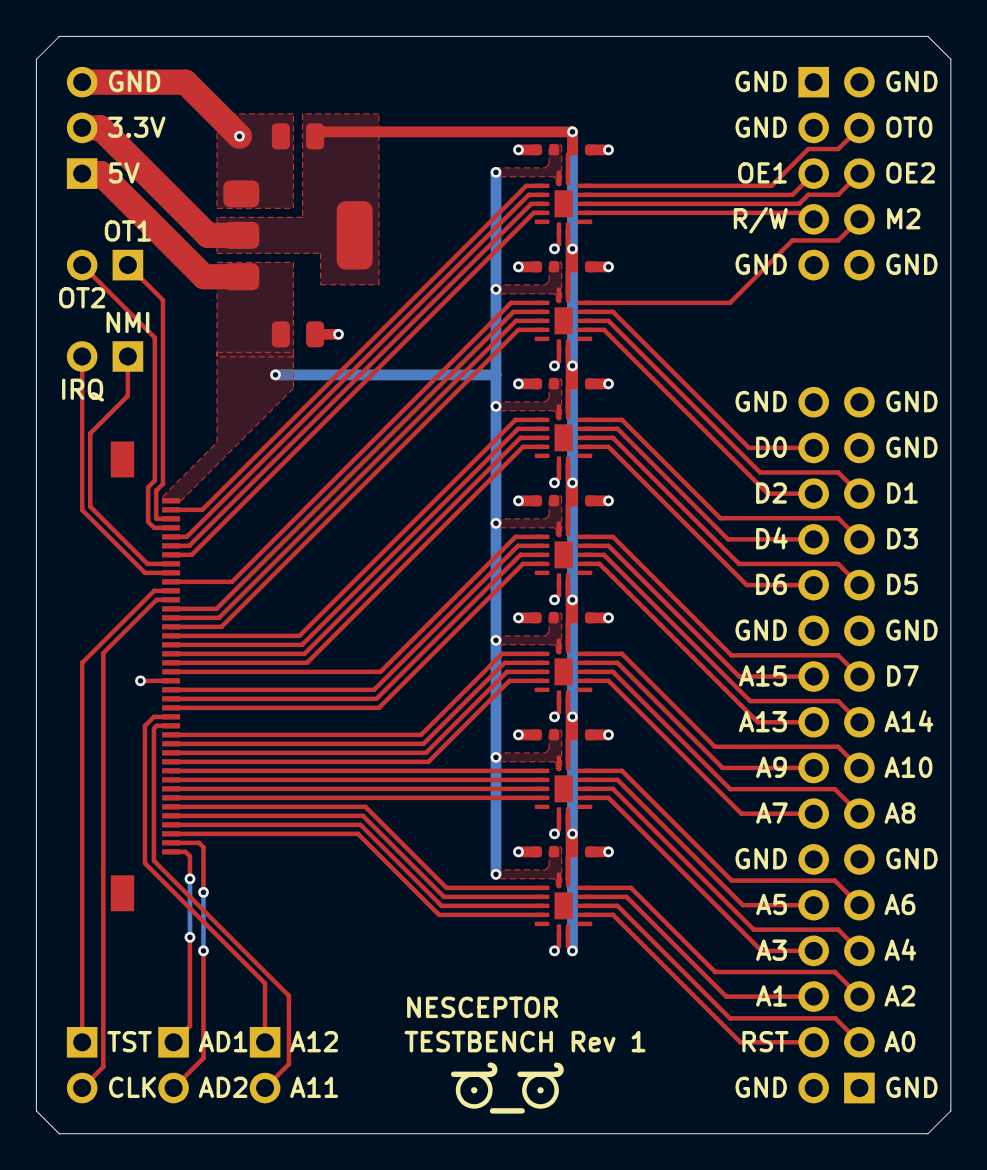
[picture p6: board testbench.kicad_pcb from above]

Board: 2 copper layers, 50.8 x 61.0 mm, 33 parts (0 on the bottom side), 69 nets.

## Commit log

2024-05-09 Add the pico-sdk submodule
2024-05-09 Add initial altium project
    [nesceptor.PcbDoc, nesceptor.PrjPcb, nesceptor.SchDoc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]
2024-05-09 Add old prototype
2025-10-06 Remove pico-sdk for now
2025-10-09 Add TLV1117LV datasheet
    I am trying this component to get a 3.3v supply for the level
    translation.
2025-10-09 Add the nesceptor kicad library for components
2025-10-09 Add the 'testbench' dev board to help develop the next major revision
    This board should help with hooking up a current NES to the logic
    analyzer and documenting those next steps. I'm sure it's silly but I
    haven't reviewed this one with a real engineer. Should show up in a few
    weeks!
    [testbench-B_Cu.gbl, testbench-B_Mask.gbs, testbench-B_Paste.gbp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]
2025-10-19 Add initial inconsole rev 0
    [inconsole-B_Cu.gbl, inconsole-B_Mask.gbs, inconsole-B_Paste.gbp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]
2025-10-19 Add missing BOM and Centroids from testbench
    [testbench_bom.csv, testbench_centroids.csv]
2025-10-21 Add an initial 3D printed enclosure for the usbport pcb
    Still need to investigate thickness in a few spots - and then need to
    get it printed and see about the threaded inserts / screws etc.
    [bottom.stl, enclosure.scad, top.stl]
2025-10-21 Add an initial usbport design based on unified daughterboards
    This is still in progress, but will be the little piece that fits
    between the main inconsole board and the outside world. Thankfully can
    steal all the good ideas from the unified daughterboard project!
    [usbport.kicad_pcb, usbport.kicad_sch]
2025-10-21 Remove altium files, as no longer used
    [nesceptor.PcbDoc, nesceptor.PrjPcb, nesceptor.SchDoc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]
2025-10-21 Add initial firmware wiring, and a hello usb example
2025-10-27 Add initial usbport rev 0 - from the unified daughterboard project
    [usbport-B_Cu.gbl, usbport-B_Mask.gbs, usbport-B_Paste.gbp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]
